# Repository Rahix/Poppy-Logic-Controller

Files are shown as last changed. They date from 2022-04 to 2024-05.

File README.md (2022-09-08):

<h2 align="center">Poppy Logic Controller</h2>
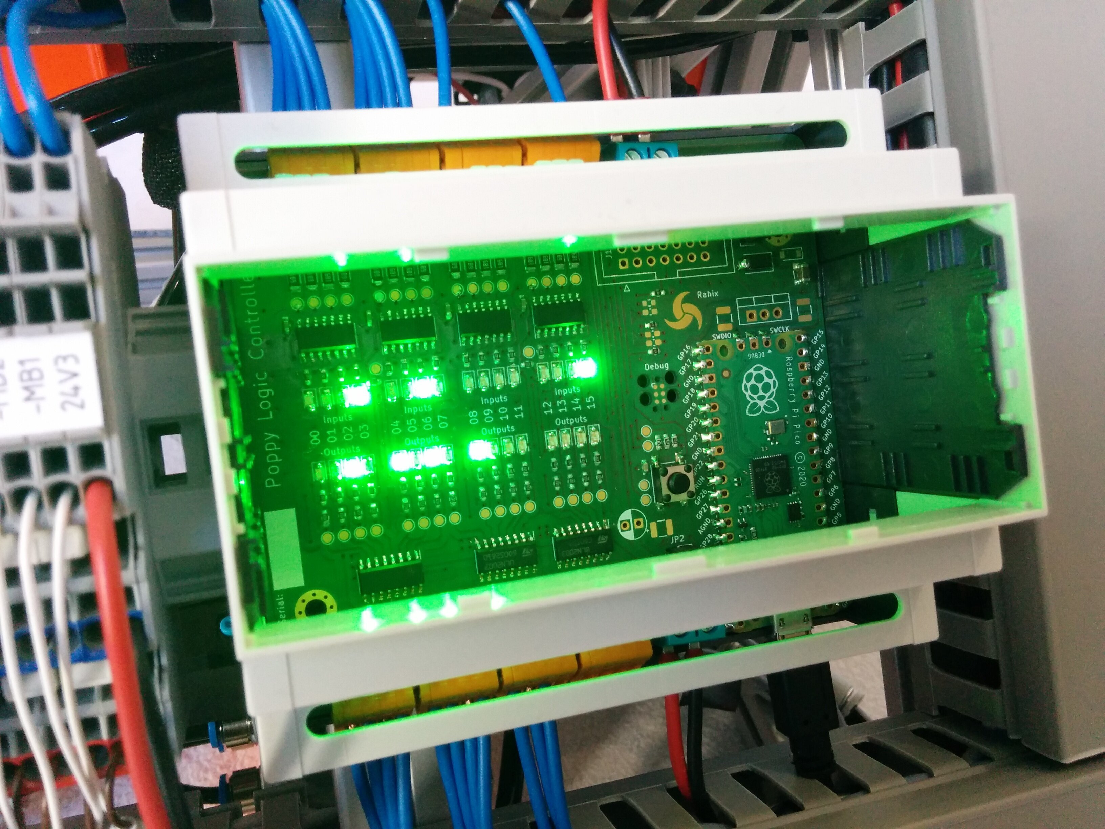
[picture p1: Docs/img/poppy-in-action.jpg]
Poppy Logic Controller


---

The _Poppy Logic Controller_ is a budget PLC (Programmable Logic Controller).
Importantly, it is only an I/O board without any PLC programming environment
(so far).  It isn't designed to be super robust but instead to use minimal
components while still staying compatible with standard industrial 24V DC
control systems.

I release the _Poppy Logic Controller_ as open hardware in hopes that others
who need a cheap solution for controlling industrial 24V DC equipment find it
useful.  _This is not a commercially viable PLC alternative._

If you want to know more about the background of this project and details of
the design, you might be interested in the blog post I wrote about it: [**Poppy
Logic Controller**][poppy-blog]

### Features
- Designed for 24V DC systems as most commonly found in modern controls
  applications.
- 16 DI (digital inputs) in a **Sinking Input** configuration.
- 16 DO (digital outputs) in a **Sinking Output** configuration.
- Firmware stubs in [Rust][fw-rust], [MicroPython][fw-mp], and [IEC 61131-3
  _Structured Text_][fw-iec].

<small>Learn more about sinking/sourcing I/O [here][realpars-input] and
[here][realpars-output] or from [my blog-post about this
project][poppy-blog].</small>

### Non-Features
- I/Os are **not** galvanically isolated.  Honestly, the isolators would
  probably be more expensive than the MCU so there is not much incentive to
  implement isolation anyway.
- The board currently does not have any communication interfaces apart from the
  Pico's USB port.  If you need to interface with anything, you might need to
  either update the board design or connect an additional mod onto the `J12`
  header.

### Building Your Own
Rendered versions of the schematic and BOM can be found here:

- [Rendered Schematic](./Docs/PoppyIO.pdf)
- [Rendered BOM](https://rahix.github.io/Poppy-Logic-Controller/Docs/PoppyIO_bom_D.html)
- [Rendered Interactive BOM](https://rahix.github.io/Poppy-Logic-Controller/Docs/PoppyIO_ibom_D.html)

#### Parts
Supplier for almost all parts of this project was [Reichelt Elektronik] (no
affiliation or sponsorship here, purely personal choice).  I've tried
reconstructing the BOM with all the Reichelt SKUs so you can painlessly get all
you need from one place if you so desire.  There is a column in the BOMs linked
above with all the information you need.

#### Additional Components
Beyond the PCB's BOM, you will need a few more components.  After all, you
probably want the nice feeling of mounting your controller on a DIN-rail, don't
you?

1. The enclosure, which is an `APRA-NORM 449-360-65` (Reichelt `APRA DB6 OBK`)
2. Optionally, a lid for the enclosure, like `APRA-NORM 449-360-12` (Reichelt
   `APRA 449-360-12`). Also available in other colors.
3. A few (2) jumpers (Reichelt `JUMPER 2,54 SW`)

#### Hardware Revisions
In the design files, you'll find the latest revision **D**.  I suggest using
that one although it is not exactly the version I have built.  My (2) boards
are built from revision **B** with one populated like revision **C** and one
populated like revision **D**.  You can read the [changelog][poppy-changelog]
for details of the differences.

#### Programming It
This repository contains a bare-bones firmware in Rust and MicroPython to get
started.  Or, if you have a background in automation, you can program the Poppy
Logic Controller in _ST_ (_Structured Text_) using the IEC 61131-3 firmware.
Check the READMEs for more info on that:

- [Firmware-Rust][fw-rust]
- [Firmware-MicroPython][fw-mp]
- [Firmware-IEC][fw-iec]

#### Not using the Pico
If you need a different microcontroller, you can drop the Raspberry Pi Pico and
instead solder the `J12` header.  You can then connect whatever controller you
desire and use the I²C bus (and interrupt lines) to interact with the I/O.

---

If you want to build your own but you are unsure or you have questions about
anything, feel free to contact me to get it sorted out!

## License
- The hardware design files (everything in `Hardware/`) are licensed under the
  [CERN-OHL-W](LICENSE-HARDWARE).
- The firmware stubs (everything in `Firmware-*/`) are licensed under
  [MIT](LICENSE-SOFTWARE).

[Reichelt Elektronik]: https://www.reichelt.de/
[poppy-blog]: https://blog.rahix.de/poppy-logic-controller/
[poppy-changelog]: ./Hardware/PoppyIO/CHANGELOG.md
[realpars-input]: https://realpars.com/sinking-and-sourcing/
[realpars-output]: https://realpars.com/sinking-output/
[fw-rust]: ./Firmware-Rust/
[fw-mp]: ./Firmware-MicroPython/
[fw-iec]: ./Firmware-IEC/

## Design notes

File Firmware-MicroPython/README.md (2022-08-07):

MicroPython Firmware for Poppy Logic Controller
-----------------------------------------------
In this directory, you can find a bare-bones MicroPython firmware for the Poppy
Logic Controller.  You can use this as a starting point for developing your own
programs.

To get started, you need to install MicroPython on the Raspberry Pi Pico.
Information about this can be found here:
<https://www.raspberrypi.com/documentation/microcontrollers/micropython.html>

Next, install the `mpremote` tool to interact with the Pico:

```bash
pin install mpremote
```

Next, if you just want to try out some code, you can upload it to the Pico like
this:

```bash
mpremote run poppy.py
```

If you want to upload the program permanently, so the Pico automatically runs
it on power-on, use this command:

```bash
mpremote cp poppy.py :main.py
```

**Note the `:` before `main.py`!**

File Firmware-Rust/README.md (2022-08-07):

Rust Firmware for Poppy Logic Controller
----------------------------------------
In this directory, you can find a bare-bones Rust firmware for the Poppy Logic
Controller.  You can use this as a starting point for developing your own
programs.

To run this firmware, first install `elf2uf2-rs`, the tool to flash firmware
onto the Raspberry Pi Pico:

```bash
cargo install elf2uf2-rs
```

Then, put the Pico into bootloader mode by first pressing the `BOOTSEL` button
and then, while keeping it held down, pressing the reset button.

Now you're ready to upload your Rust program using a simple

```bash
cargo run
```

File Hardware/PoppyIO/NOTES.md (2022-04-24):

Notes & ToDo List for the IO Board
==================================

### Inputs
- [x] Indicator LEDs
- [x] LED series resistor verification: ~1mA
- [x] ESD safety: 74VHC14 has protection
- [x] Re-verify current and voltage
- [x] Verify limiting values: Maximum input voltage for 5.5V out is 27.6V.
  Limiting value (7V) is reached at 35V.
- [x] Verify logic step-down:  Multiple 74VHC14 data-sheets mention that it can
  be used to step down to Vcc.
- [x] Defined initial state for inverters?
  - 680R pulls down to GND

### Outputs
- [x] Indicator LEDs
- [x] LED series resistor verification ~1mA
- [x] Driver: ULN2003A
- [x] Compatibility with inductive loads
  - Compatible as long as 24V supply is connected (freewheeling diodes included
    in driver package).
- [x] Check drive capability of port-expander (LEDs + drivers)
- [x] ESD safety: ULN2003A has protection
- [x] defined initial state for drivers?
  - Added 10k pull-downs.
- [x] Must use a smaller polyfuse footprint

### Power Supply
- [x] Add 24V to 5/3.3V step down or power from 5V?
- [x] Screw-in terminals: Using Phoenix screw terminals for power

### Pico MCU
- [x] Reset Button
- [x] Additional IO?
  - Added a UART for the second board, just in case.

### Misc
- [x] I2C addresses
- [x] Mounting holes
- [x] Board-to-Board Connector Pinout

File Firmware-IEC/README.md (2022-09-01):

IEC 61131-3 Firmware for Poppy Logic Controller
-----------------------------------------------
The firmware in this directory allows writing control programs for the Poppy
Logic Controller in the IEC 61131-3 textual language _ST_ (_Structured Text_).

This is made possible by the [matiec] open-source 61131-3 compiler.  This
compiler is used to compile the _ST_ code into the C language from where it
is then linked against a Rust firmware which drives the I/O.

### Running It
The build process is entirely driven by cargo.  [matiec] is installed
automatically on first build.  The only dependency you need is, as for the Rust
firmware, `elf2uf2-rs`:

```bash
cargo install elf2uf2-rs
```

Then, put the Pico into bootloader mode by first pressing the `BOOTSEL` button
and then, while keeping it held down, pressing the reset button.

Now you can build and deploy your 61131-3 firmware:

```bash
cargo run
```

### Programming Quickstart
You might want to read up on the basics of _ST_ somewhere first.  I am going to
detail some [matiec] and Poppy Logic specific things in this section of the
README.

The program is found in [`src/main.st`][main.st].  In contrast to a lot of PLC
programming IDEs, the entire _ST_ program must be written here, including the
top-level program and configuration (which is usually handled in GUI).  You can
take the existing code as a basis. Your top-level code goes into the body of
the `PROGRAM`.

Further tasks and function blocks can also be added to `main.st`.
Alternatively, you can put them in separate files and include those using:

```text
{#include "filename.st"}
```

For I/O, the following tags exist and map to the Poppy Logic Controllers 16
inputs and 16 outputs:

- Inputs: `%IX00`, `%IX01`, `%IX02`, `%IX03`, `%IX04`, `%IX05`, `%IX06`,
  `%IX07`, `%IX08`, `%IX09`, `%IX10`, `%IX11`, `%IX12`, `%IX13`, `%IX14`,
  `%IX15`
- Outputs: `%QX00`, `%QX01`, `%QX02`, `%QX03`, `%QX04`, `%QX05`, `%QX06`,
  `%QX07`, `%QX08`, `%QX09`, `%QX10`, `%QX11`, `%QX12`, `%QX13`, `%QX14`,
  `%QX15`

Byte-access or word-access to these tags is not possible.

### Modbus
This firmware also comes with a [Modbus RTU] interface for interaction with
other devices.  The interface is available over USB, where the Poppy Logic
Controller will announce itself as a serial port.

A few registers are mapped to Modbus for communication:

- Modbus Coils 0 - 15 of unit 1 are mapped to `%MX00` - `%MX15`.
- Modbus Holding Registers 0 - 15 of unit 1 are mapped to `%MW00` - `%MW15`.
  Holding registers are 16 bits wide.

Additionally, the state of all inputs and outputs is available _read-only_
through Modbus discrete inputs:

- Inputs `%IX00` - `%IX15` are mapped to discrete inputs 0 - 15.
- Outputs `%QX00` - `%QX15` are mapped to discrete inputs 16 - 31.

(This may be useful for visualization purposes).

As a quick example, using the [pymodbus REPL] you can set coils or dump the
state of inputs and outputs:

```console
$ pymodbus.console serial --port /dev/ttyACM0

> # Set a coil
> client.write_coil unit=1 address=0 value=1
> # And reset it again
> client.write_coil unit=1 address=0 value=0

> # Or dump all physical inputs and outputs
> client.read_discrete_inputs unit=1 address=0 count=32
{
    "bits": [
        false,
        false,
        ...
```

### Modbus Monitor GUI Example
To demonstrate the Modbus communication, I added a small GUI example:
[`modbus_monitor.py`](./modbus_monitor.py)

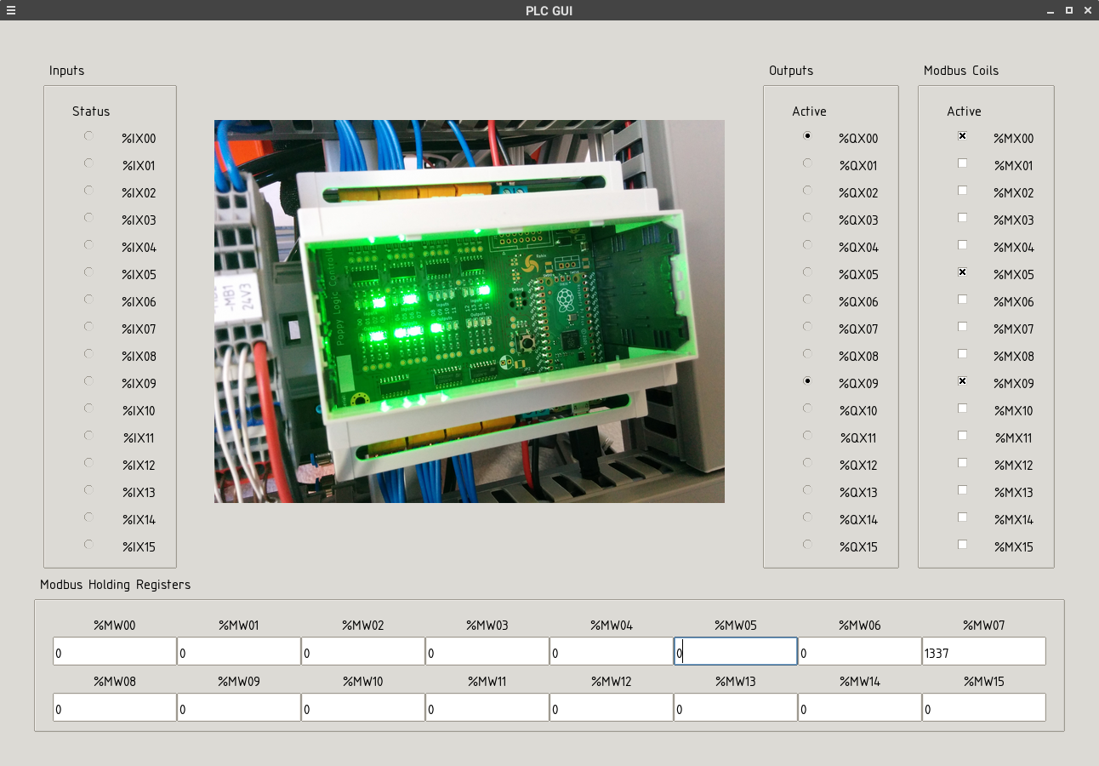
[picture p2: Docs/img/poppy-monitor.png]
Image of the GUI


[matiec]: https://github.com/beremiz/matiec
[main.st]: src/main.st
[Modbus RTU]: https://en.wikipedia.org/wiki/Modbus
[pymodbus REPL]: https://pymodbus.readthedocs.io/en/latest/source/library/REPL.html

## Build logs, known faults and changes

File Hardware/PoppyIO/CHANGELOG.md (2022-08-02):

## Revision D - 2022-08-02
- Drop _DNP_ note from LM78xx regulator and its capacitors.  The regulator is
  used to step-down the 24V input to 5V for the Raspberry Pi Pico.  Not using
  the regulator means a separate 5V supply is needed which is pretty pointless.
- Removed the screw-terminal J9 for an external 5V supply.
- Switched Screw-Terminal for 24V supply to a 2-pin variant.

## Revision C - 2022-06-26
- Fixup wrong resistor values in DI stage.  The 680Ω resistors were meant to be
  820Ω from the beginning but this was not copied correctly.  With the wrong
  value, the DI limiting values are slightly off from what is specified in the
  schematic.

## Revision B - 2022-04-25
- Switch to a 14-pin IDC connector.

## Revision A - 2022-04-24
Initial.

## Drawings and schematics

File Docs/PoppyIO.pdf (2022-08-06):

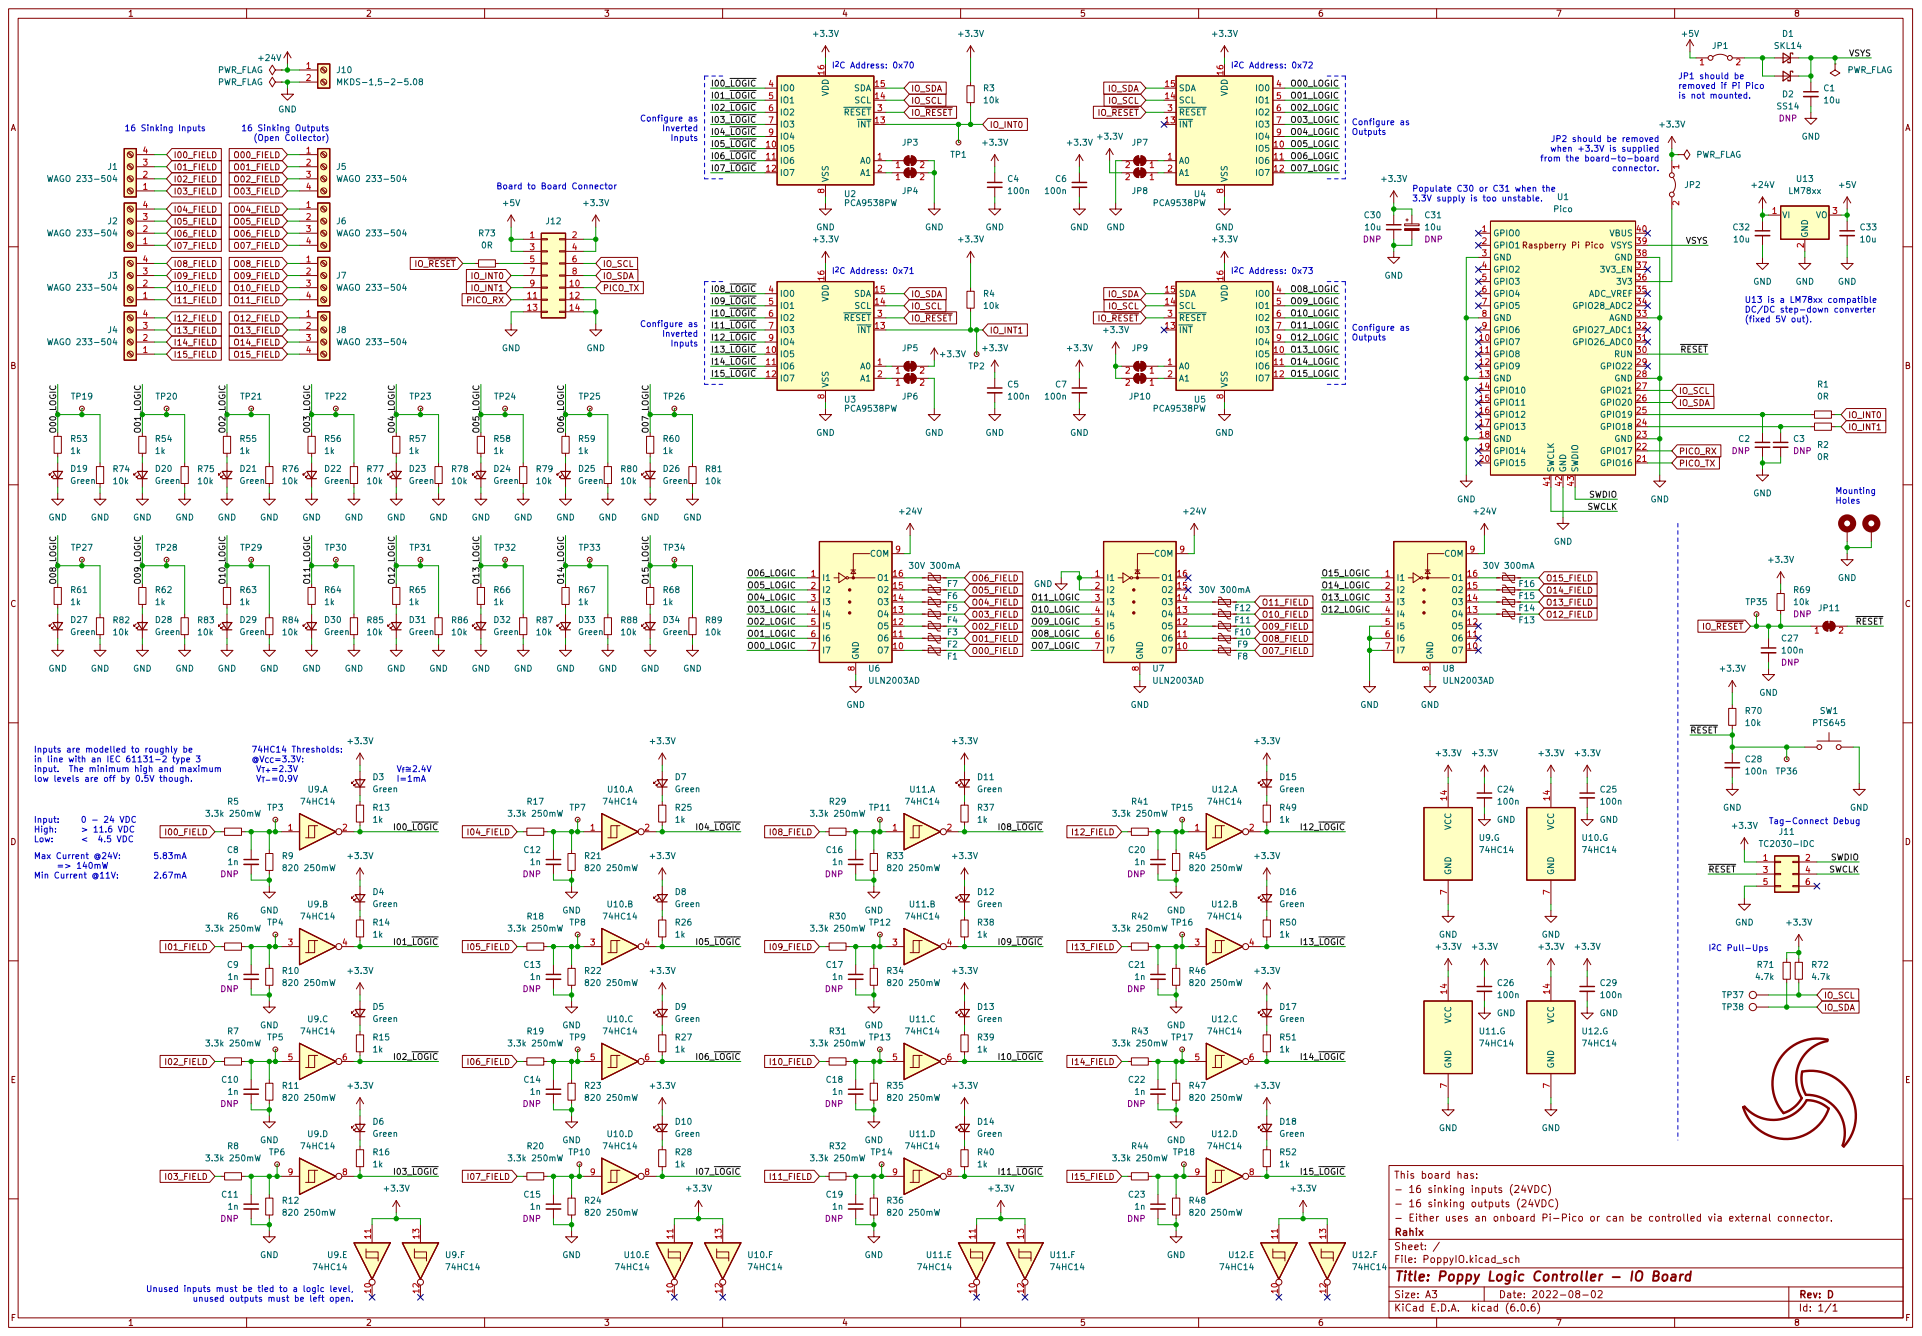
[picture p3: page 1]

removed if Pi Pico
is not mounted.

JP2 should be removed when +3.3V is supplied

from the board-to-board

U13 is a LM78xx compatible
DC/DC step-down converter
(fixed 5V out).
C3 DNP R1

Inputs are modelled to roughly be
in line with an IEC 61131-2 type 3
input. The minimum high and maximum
low levels are off by 0.5V though.

- 16 sinking inputs (24VDC) This board has:

- Either uses an onboard Pi-Pico or can be controlled via external connector. - 16 sinking outputs (24VDC)

File: PoppyIO.kicad_sch Sheet: / Rahix

Id: 1/1 Title: Poppy Logic Controller - IO Board

Unused inputs must be tied to a logic level,

unused outputs must be left open.

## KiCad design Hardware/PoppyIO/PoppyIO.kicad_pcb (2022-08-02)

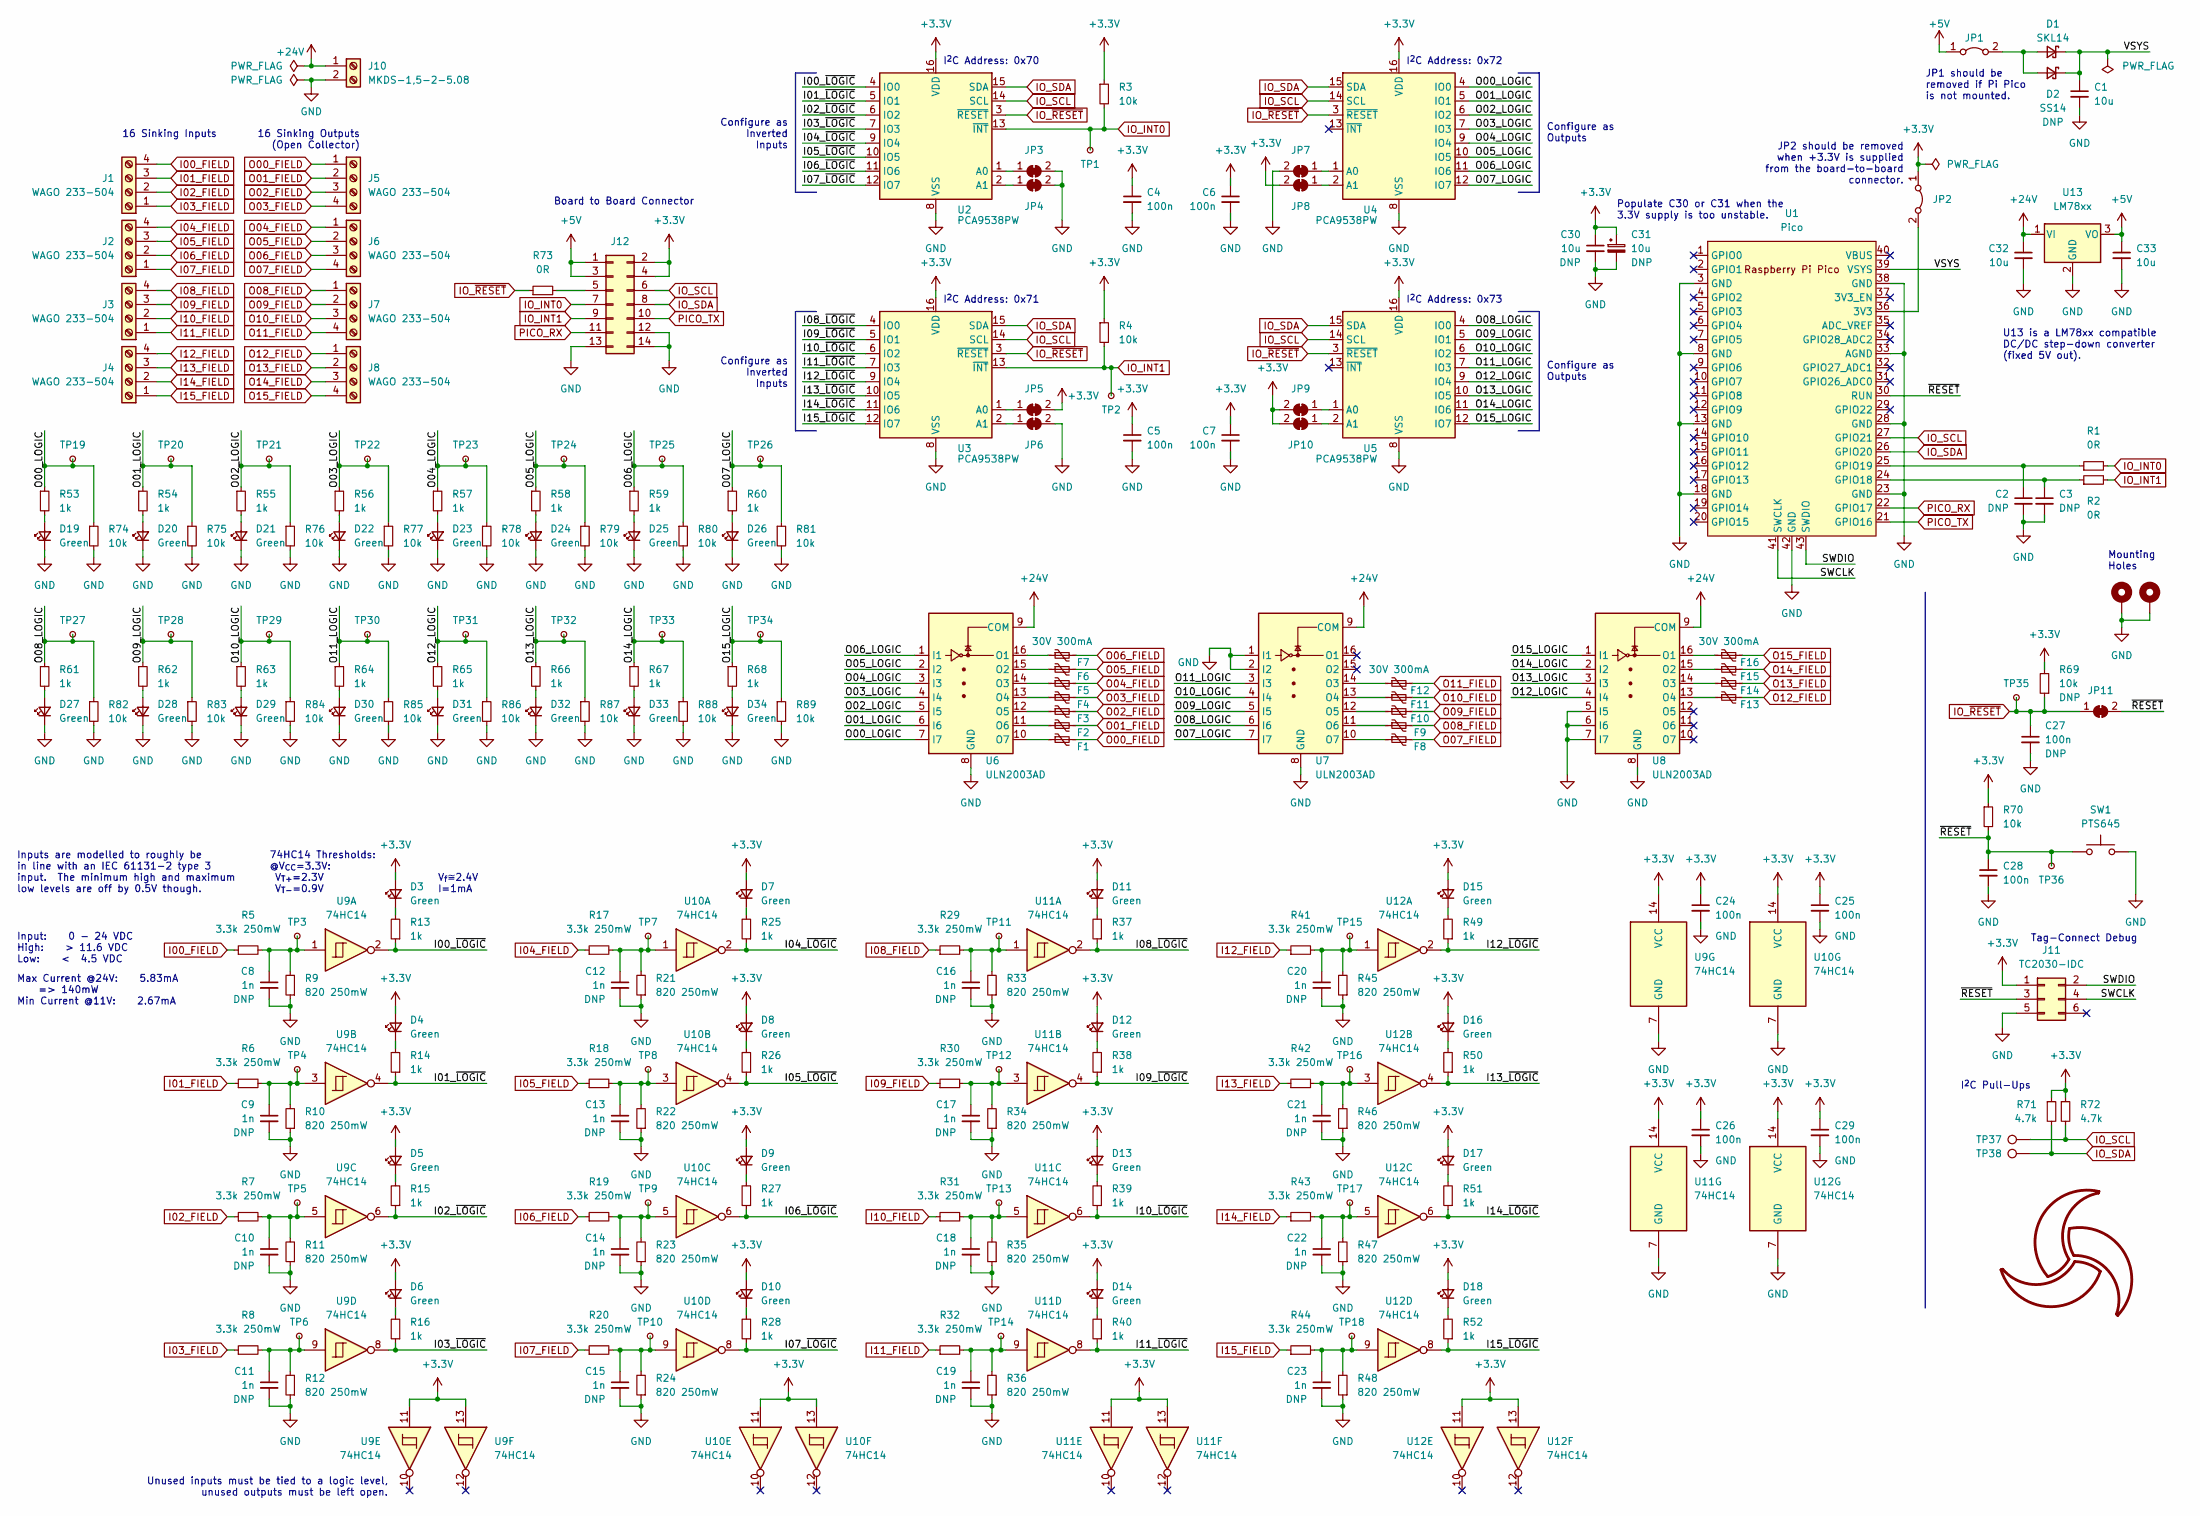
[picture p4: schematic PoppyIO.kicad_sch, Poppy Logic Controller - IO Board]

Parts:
C1, C30, C32, C33: 10u; C_1210_3225Metric
C2, C3: C_0603_1608Metric_Pad1.08x0.95mm_HandSolder
C4, C5, C6, C7, C24, C25, C26, C27, C28, C29: 100n; C_0603_1608Metric_Pad1.08x0.95mm_HandSolder
C8, C9, C10, C11, C12, C13, C14, C15, C16, C17, C18, C19, C20, C21, C22, C23: 1n; C_0805_2012Metric
C31: 10u; CP_Radial_D5.0mm_P2.50mm
D1: SKL14; D_SOD-123
D2: SS14; D_SMA
D3, D4, D5, D6, D7, D8, D9, D10, D11, D12, D13, D14, D15, D16, D17, D18, D19, D20, D21, D22, D23, D24, D25, D26, D27, D28, D29, D30, D31, D32, D33, D34: Green; LED_0805_2012Metric_Pad1.15x1.40mm_HandSolder
F1, F2, F3, F4, F5, F6, F7, F8, F9, F10, F11, F12, F13, F14, F15, F16: 30V 300mA; Fuse_1210_3225Metric_Pad1.42x2.65mm_HandSolder
H1, H2: MountingHole_Pad; MountingHole_3.2mm_M3_Pad_Via
J1, J2, J3, J4, J5, J6, J7, J8: WAGO 233-504; WAGO_233-204
J10: MKDS-1,5-2-5.08; TerminalBlock_Phoenix_MKDS-1,5-2-5.08_1x02_P5.08mm_Horizont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
J11: TC2030-IDC; Tag-Connect_TC2030-IDC-FP_2x03_P1.27mm_Vertical
J12: Conn_02x07_Odd_Even; IDC-Header_2x07_P2.54mm_Vertical
JP1, JP2: PinHeader_1x02_P2.54mm_Vertical
JP3, JP4, JP5, JP6, JP7, JP8, JP9, JP10, JP11: SolderJumper_2_Bridged; SolderJumper-2_P1.3mm_Bridged_RoundedPad1.0x1.5mm
R1, R2, R73: 0R; R_0603_1608Metric
R3, R4, R69, R70, R74, R75, R76, R77, R78, R79, R80, R81, R82, R83, R84, R85, R86, R87, R88, R89: 10k; R_0603_1608Metric
R5, R6, R7, R8, R17, R18, R19, R20, R29, R30, R31, R32, R41, R42, R43, R44: 3.3k 250mW; R_1206_3216Metric
R9, R10, R11, R12, R21, R22, R23, R24, R33, R34, R35, R36, R45, R46, R47, R48: 820 250mW; R_1206_3216Metric
R13, R14, R15, R16, R25, R26, R27, R28, R37, R38, R39, R40, R49, R50, R51, R52, R53, R54, R55, R56, R57, R58, R59, R60, R61, R62, R63, R64, R65, R66, R67, R68: 1k; R_0603_1608Metric
R71, R72: 4.7k; R_0603_1608Metric_Pad0.98x0.95mm_HandSolder
SW1: PTS645; SW_SPST_PTS645
SYM1: SYM_Rahix
TP1, TP2, TP3, TP4, TP5, TP6, TP7, TP8, TP9, TP10, TP11, TP12, TP13, TP14, TP15, TP16, TP17, TP18, TP19, TP20, TP21, TP22, TP23, TP24, TP25, TP26, TP27, TP28, TP29, TP30, TP31, TP32, TP33, TP34, TP35, TP36: TestPoint_Small; TestPoint_Pad_D1.5mm
TP37, TP38: TestPoint; TestPoint_Pad_D1.5mm
U1: Pico; RPi_Pico_SMD_TH
U2, U3, U4, U5: PCA9538PW; TSSOP-16_4.4x5mm_P0.65mm
U6, U7, U8: ULN2003AD; SOIC-16_3.9x9.9mm_P1.27mm
U9, U10, U11, U12: 74HC14; SOIC-14_3.9x8.7mm_P1.27mm
U13: LM78xx; TO-220-3_Vertical_Clearance

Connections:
+3.3V: C4.1, C5.1, C6.1, C7.1, C24.1, C25.1, C26.1, C29.1, C30.1, C31.1, D3.2 (A), D4.2 (A), D5.2 (A), D6.2 (A), D7.2 (A), D8.2 (A), D9.2 (A), D10.2 (A), D11.2 (A), D12.2 (A), D13.2 (A), D14.2 (A), D15.2 (A), D16.2 (A), D17.2 (A), D18.2 (A), J11.1, J12.2, J12.4, JP2.1 (A), JP5.2 (B), JP8.2 (B), JP9.2 (B), JP10.2 (B), R3.1, R4.1, R69.2, R70.1, R71.1, R72.1, U2.16 (VDD), U3.16 (VDD), U4.16 (VDD), U5.16 (VDD), U9.11, U9.13, U9.14 (VCC), U10.11, U10.13, U10.14 (VCC), U11.11, U11.13, U11.14 (VCC), U12.11, U12.13, U12.14 (VCC)
+5V: C33.1, J12.1, J12.3, JP1.1 (A), U13.3 (VO)
+24V: C32.1, J10.1, U6.9 (COM), U7.9 (COM), U8.9 (COM), U13.1 (VI)
/I00_~LOGIC: R13.1, U2.4 (IO0), U9.2
/I01_~LOGIC: R14.1, U2.5 (IO1), U9.4
/I02_~LOGIC: R15.1, U2.6 (IO2), U9.6
/I03_~LOGIC: R16.1, U2.7 (IO3), U9.8
/I04_~LOGIC: R25.1, U2.9 (IO4), U10.2
/I05_~LOGIC: R26.1, U2.10 (IO5), U10.4
/I06_~LOGIC: R27.1, U2.11 (IO6), U10.6
/I07_~LOGIC: R28.1, U2.12 (IO7), U10.8
/I08_~LOGIC: R37.1, U3.4 (IO0), U11.2
/I09_~LOGIC: R38.1, U3.5 (IO1), U11.4
/I10_~LOGIC: R39.1, U3.6 (IO2), U11.6
/I11_~LOGIC: R40.1, U3.7 (IO3), U11.8
/I12_~LOGIC: R49.1, U3.9 (IO4), U12.2
/I13_~LOGIC: R50.1, U3.10 (IO5), U12.4
/I14_~LOGIC: R51.1, U3.11 (IO6), U12.6
/I15_~LOGIC: R52.1, U3.12 (IO7), U12.8
/O00_LOGIC: R53.1, R74.1, TP19.1, U4.4 (IO0), U6.7 (I7)
/O01_LOGIC: R54.1, R75.1, TP20.1, U4.5 (IO1), U6.6 (I6)
/O02_LOGIC: R55.1, R76.1, TP21.1, U4.6 (IO2), U6.5 (I5)
/O03_LOGIC: R56.1, R77.1, TP22.1, U4.7 (IO3), U6.4 (I4)
/O04_LOGIC: R57.1, R78.1, TP23.1, U4.9 (IO4), U6.3 (I3)
/O05_LOGIC: R58.1, R79.1, TP24.1, U4.10 (IO5), U6.2 (I2)
/O06_LOGIC: R59.1, R80.1, TP25.1, U4.11 (IO6), U6.1 (I1)
/O07_LOGIC: R60.1, R81.1, TP26.1, U4.12 (IO7), U7.7 (I7)
/O08_LOGIC: R61.1, R82.1, TP27.1, U5.4 (IO0), U7.6 (I6)
/O09_LOGIC: R62.1, R83.1, TP28.1, U5.5 (IO1), U7.5 (I5)
/O10_LOGIC: R63.1, R84.1, TP29.1, U5.6 (IO2), U7.4 (I4)
/O11_LOGIC: R64.1, R85.1, TP30.1, U5.7 (IO3), U7.3 (I3)
/O12_LOGIC: R65.1, R86.1, TP31.1, U5.9 (IO4), U8.4 (I4)
/O13_LOGIC: R66.1, R87.1, TP32.1, U5.10 (IO5), U8.3 (I3)
/O14_LOGIC: R67.1, R88.1, TP33.1, U5.11 (IO6), U8.2 (I2)
/O15_LOGIC: R68.1, R89.1, TP34.1, U5.12 (IO7), U8.1 (I1)
/SWCLK: J11.4, U1.41 (SWCLK)
/SWDIO: J11.2, U1.43 (SWDIO)
/VSYS: C1.1, D1.1 (K), D2.1 (K), U1.39 (VSYS)
/~RESET: C28.1, J11.3, JP11.2 (B), R70.2, SW1.1, TP36.1, U1.30 (RUN)
GND: C1.2, C2.2, C3.2, C4.2, C5.2, C6.2, C7.2, C8.2, C9.2, C10.2, C11.2, C12.2, C13.2, C14.2, C15.2, C16.2, C17.2, C18.2, C19.2, C20.2, C21.2, C22.2, C23.2, C24.2, C25.2, C26.2, C27.2, C28.2, C29.2, C30.2, C31.2, C32.2, C33.2, D19.1 (K), D20.1 (K), D21.1 (K), D22.1 (K), D23.1 (K), D24.1 (K), D25.1 (K), D26.1 (K), D27.1 (K), D28.1 (K), D29.1 (K), D30.1 (K), D31.1 (K), D32.1 (K), D33.1 (K), D34.1 (K), H1.1, H2.1, J10.2, J11.5, J12.12, J12.13, J12.14, JP3.2 (B), JP4.2 (B), JP6.2 (B), JP7.2 (B), R9.1, R10.1, R11.1, R12.1, R21.1, R22.1, R23.1, R24.1, R33.1, R34.1, R35.1, R36.1, R45.1, R46.1, R47.1, R48.1, R74.2, R75.2, R76.2, R77.2, R78.2, R79.2, R80.2, R81.2, R82.2, R83.2, R84.2, R85.2, R86.2, R87.2, R88.2, R89.2, SW1.2, U1.3 (GND), U1.8 (GND), U1.13 (GND), U1.18 (GND), U1.23 (GND), U1.28 (GND), U1.33 (AGND), U1.38 (GND), U1.42 (GND), U2.8 (VSS), U3.8 (VSS), U4.8 (VSS), U5.8 (VSS), U6.8 (GND), U7.1 (I1), U7.2 (I2), U7.8 (GND), U8.5 (I5), U8.6 (I6), U8.7 (I7), U8.8 (GND), U9.7 (GND), U10.7 (GND), U11.7 (GND), U12.7 (GND), U13.2 (GND)
I00_FIELD: J1.4, R5.1
I01_FIELD: J1.3, R6.1
I02_FIELD: J1.2, R7.1
I03_FIELD: J1.1, R8.1
I04_FIELD: J2.4, R17.1
I05_FIELD: J2.3, R18.1
I06_FIELD: J2.2, R19.1
I07_FIELD: J2.1, R20.1
I08_FIELD: J3.4, R29.1
I09_FIELD: J3.3, R30.1
I10_FIELD: J3.2, R31.1
I11_FIELD: J3.1, R32.1
I12_FIELD: J4.4, R41.1
I13_FIELD: J4.3, R42.1
I14_FIELD: J4.2, R43.1
I15_FIELD: J4.1, R44.1
IO_INT0: J12.7, R1.2, R3.2, TP1.1, U2.13 (~INT)
IO_INT1: J12.9, R2.2, R4.2, TP2.1, U3.13 (~INT)
IO_SCL: J12.6, R72.2, TP37.1, U1.27 (GPIO21), U2.14 (SCL), U3.14 (SCL), U4.14 (SCL), U5.14 (SCL)
IO_SDA: J12.8, R71.2, TP38.1, U1.26 (GPIO20), U2.15 (SDA), U3.15 (SDA), U4.15 (SDA), U5.15 (SDA)
IO_~RESET: C27.1, JP11.1 (A), R69.1, R73.1, TP35.1, U2.3 (~RESET), U3.3 (~RESET), U4.3 (~RESET), U5.3 (~RESET)
unnamed: C2.1, R1.1, U1.25 (GPIO19)
unnamed: C3.1, R2.1, U1.24 (GPIO18)
unnamed: C8.1, R5.2, R9.2, TP3.1, U9.1
unnamed: C9.1, R6.2, R10.2, TP4.1, U9.3
unnamed: C10.1, R7.2, R11.2, TP5.1, U9.5
unnamed: C11.1, R8.2, R12.2, TP6.1, U9.9
unnamed: C12.1, R17.2, R21.2, TP7.1, U10.1
unnamed: C13.1, R18.2, R22.2, TP8.1, U10.3
unnamed: C14.1, R19.2, R23.2, TP9.1, U10.5
unnamed: C15.1, R20.2, R24.2, TP10.1, U10.9
unnamed: C16.1, R29.2, R33.2, TP11.1, U11.1
unnamed: C17.1, R30.2, R34.2, TP12.1, U11.3
unnamed: C18.1, R31.2, R35.2, TP13.1, U11.5
unnamed: C19.1, R32.2, R36.2, TP14.1, U11.9
unnamed: C20.1, R41.2, R45.2, TP15.1, U12.1
unnamed: C21.1, R42.2, R46.2, TP16.1, U12.3
unnamed: C22.1, R43.2, R47.2, TP17.1, U12.5
unnamed: C23.1, R44.2, R48.2, TP18.1, U12.9
unnamed: D1.2 (A), D2.2 (A), JP1.2 (B)
unnamed: D3.1 (K), R13.2
unnamed: D4.1 (K), R14.2
unnamed: D5.1 (K), R15.2
unnamed: D6.1 (K), R16.2
unnamed: D7.1 (K), R25.2
unnamed: D8.1 (K), R26.2
unnamed: D9.1 (K), R27.2
unnamed: D10.1 (K), R28.2
unnamed: D11.1 (K), R37.2
unnamed: D12.1 (K), R38.2
unnamed: D13.1 (K), R39.2
unnamed: D14.1 (K), R40.2
unnamed: D15.1 (K), R49.2
unnamed: D16.1 (K), R50.2
unnamed: D17.1 (K), R51.2
unnamed: D18.1 (K), R52.2
unnamed: D19.2 (A), R53.2
unnamed: D20.2 (A), R54.2
unnamed: D21.2 (A), R55.2
unnamed: D22.2 (A), R56.2
unnamed: D23.2 (A), R57.2
unnamed: D24.2 (A), R58.2
unnamed: D25.2 (A), R59.2
unnamed: D26.2 (A), R60.2
unnamed: D27.2 (A), R61.2
unnamed: D28.2 (A), R62.2
unnamed: D29.2 (A), R63.2
unnamed: D30.2 (A), R64.2
unnamed: D31.2 (A), R65.2
unnamed: D32.2 (A), R66.2
unnamed: D33.2 (A), R67.2
unnamed: D34.2 (A), R68.2
unnamed: F1.1, U6.10 (O7)
unnamed: F2.1, U6.11 (O6)
unnamed: F3.1, U6.12 (O5)
unnamed: F4.1, U6.13 (O4)
unnamed: F5.1, U6.14 (O3)
unnamed: F6.1, U6.15 (O2)
unnamed: F7.1, U6.16 (O1)
unnamed: F8.1, U7.10 (O7)
unnamed: F9.1, U7.11 (O6)
unnamed: F10.1, U7.12 (O5)
unnamed: F11.1, U7.13 (O4)
unnamed: F12.1, U7.14 (O3)
unnamed: F13.1, U8.13 (O4)
unnamed: F14.1, U8.14 (O3)
unnamed: F15.1, U8.15 (O2)
unnamed: F16.1, U8.16 (O1)
unnamed: J12.5, R73.2
unnamed: JP2.2 (B), U1.36 (3V3)
unnamed: JP3.1 (A), U2.1 (A0)
unnamed: JP4.1 (A), U2.2 (A1)
unnamed: JP5.1 (A), U3.1 (A0)
unnamed: JP6.1 (A), U3.2 (A1)
unnamed: JP7.1 (A), U4.1 (A0)
unnamed: JP8.1 (A), U4.2 (A1)
unnamed: JP9.1 (A), U5.1 (A0)
unnamed: JP10.1 (A), U5.2 (A1)
O00_FIELD: F1.2, J5.1
O01_FIELD: F2.2, J5.2
O02_FIELD: F3.2, J5.3
O03_FIELD: F4.2, J5.4
O04_FIELD: F5.2, J6.1
O05_FIELD: F6.2, J6.2
O06_FIELD: F7.2, J6.3
O07_FIELD: F8.2, J6.4
O08_FIELD: F9.2, J7.1
O09_FIELD: F10.2, J7.2
O10_FIELD: F11.2, J7.3
O11_FIELD: F12.2, J7.4
O12_FIELD: F13.2, J8.1
O13_FIELD: F14.2, J8.2
O14_FIELD: F15.2, J8.3
O15_FIELD: F16.2, J8.4
PICO_RX: J12.11, U1.22 (GPIO17)
PICO_TX: J12.10, U1.21 (GPIO16)

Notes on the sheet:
Configure as Outputs
16 Sinking Inputs
Input: 0 - 24 VDC High: > 11.6 VDC Low: < 4.5 VDC
U13 is a LM78xx compatible DC/DC step-down converter (fixed 5V out).
JP1 should be removed if Pi Pico is not mounted.
Inputs are modelled to roughly be in line with an IEC 61131-2 type 3 input. The minimum high and maximum low levels are off by 0.5V though.
Unused inputs must be tied to a logic level, unused outputs must be left open.
I^{2}C Address: 0x70
I^{2}C Address: 0x73
I^{2}C Address: 0x72
74HC14 Thresholds: @V_{CC}=3.3V: V_{T+}=2.3V V_{T-}=0.9V
I^{2}C Address: 0x71
Tag-Connect Debug
Max Current @24V: 5.83mA => 140mW Min Current @11V: 2.67mA
Board to Board Connector
Configure as Inverted Inputs
I^{2}C Pull-Ups
16 Sinking Outputs (Open Collector)
Populate C30 or C31 when the 3.3V supply is too unstable.
V_{f}≅2.4V I=1mA
JP2 should be removed when +3.3V is supplied from the board-to-board connector.
Mounting Holes

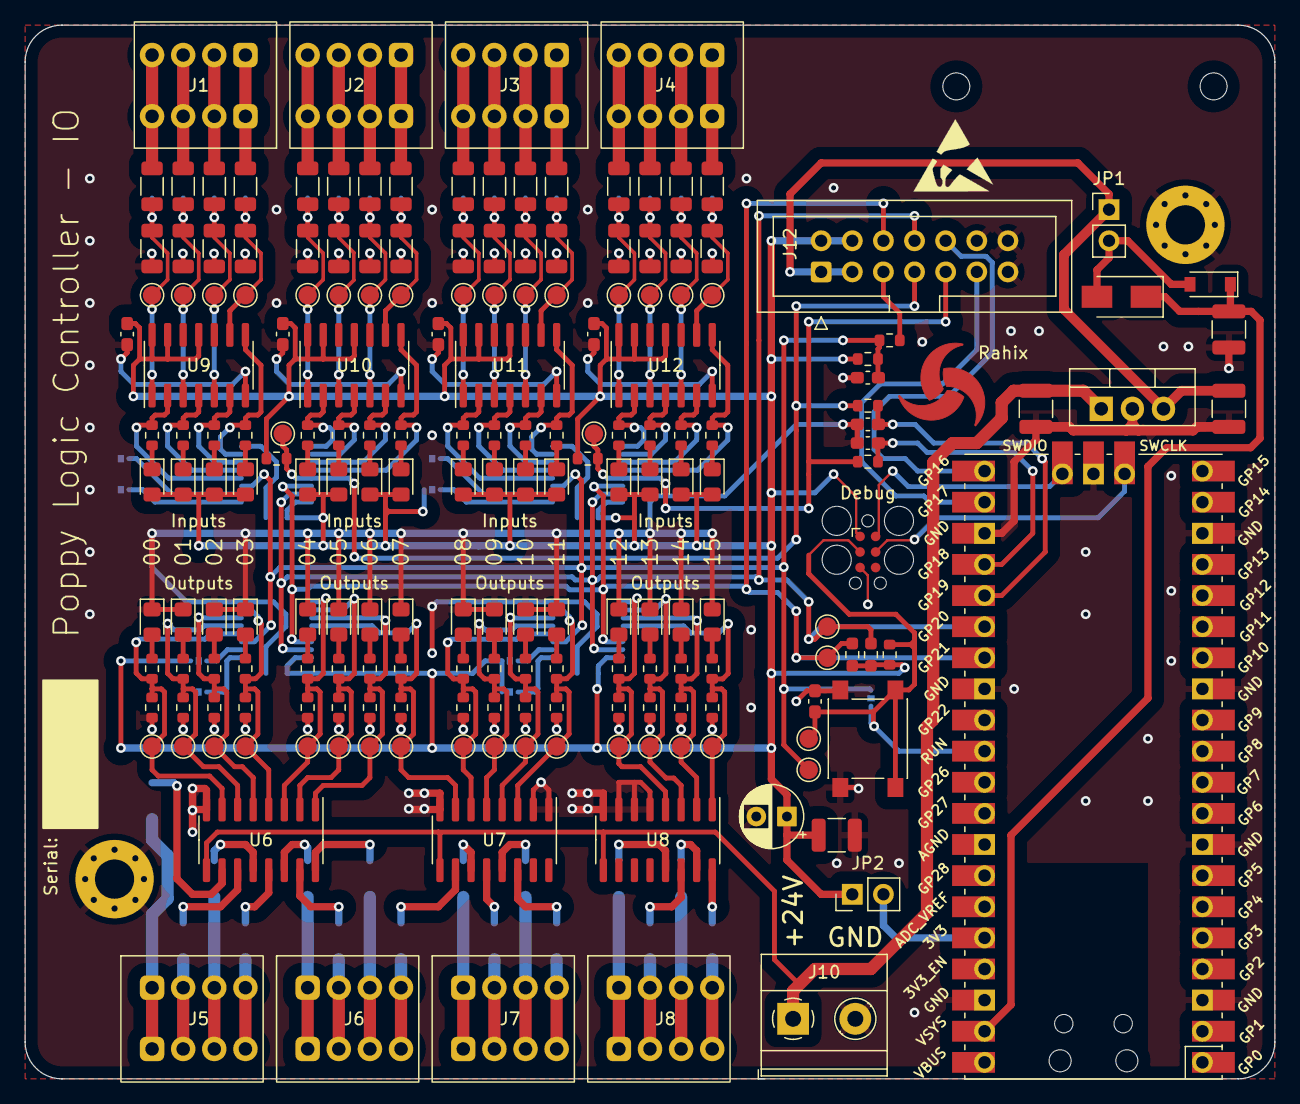
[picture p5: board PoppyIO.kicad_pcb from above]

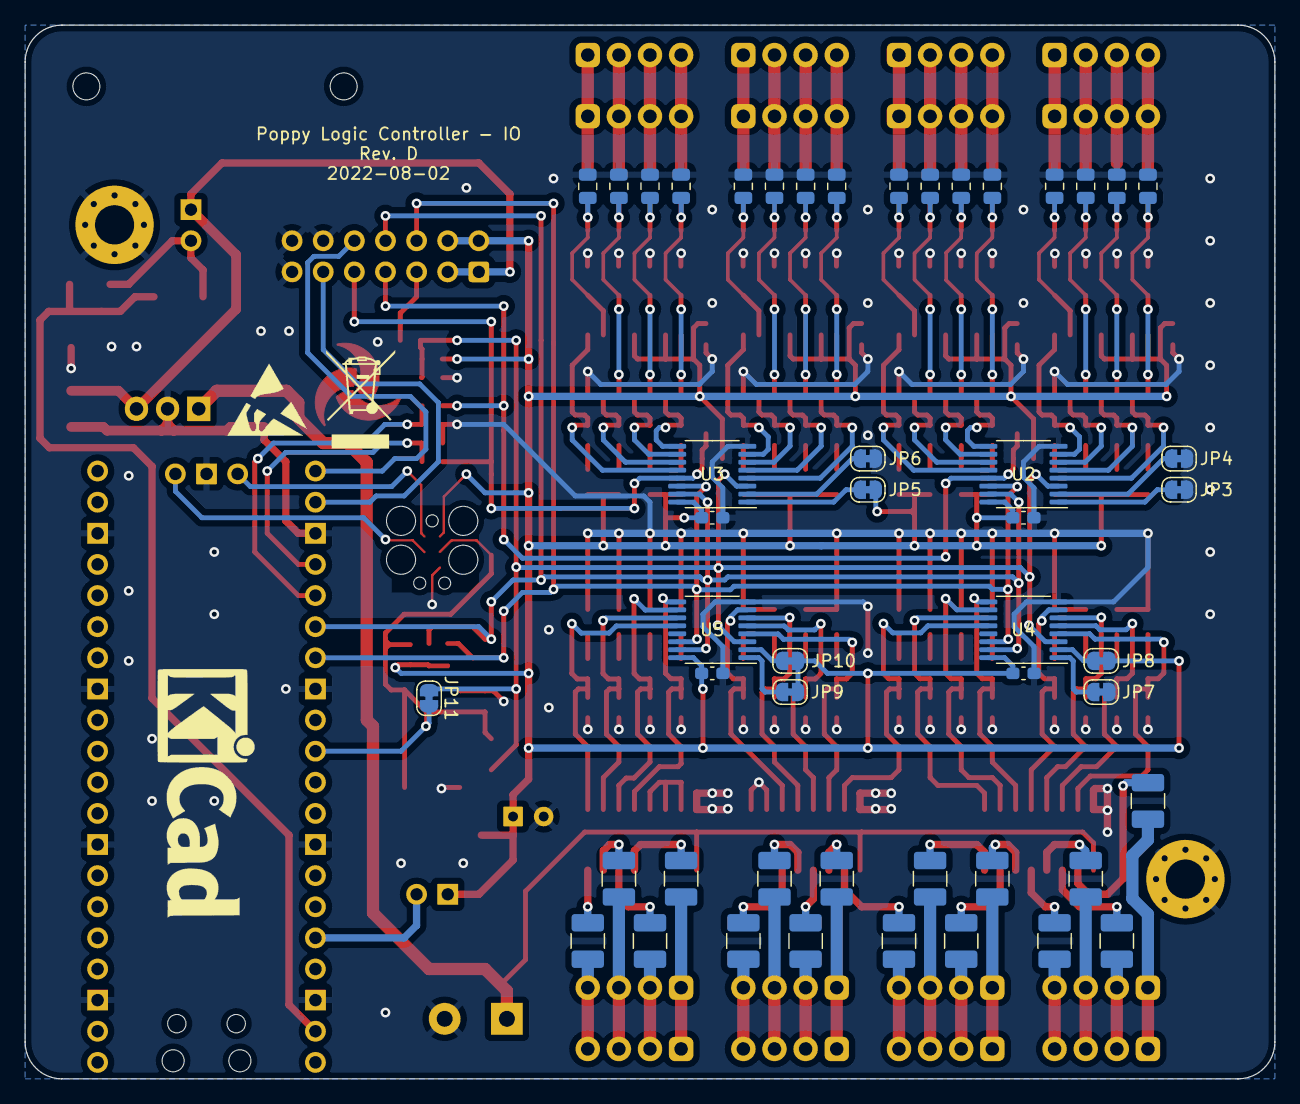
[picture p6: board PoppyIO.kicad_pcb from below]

Board: 2 copper layers, 102.0 x 86.0 mm, 249 parts (49 on the bottom side), 156 nets.

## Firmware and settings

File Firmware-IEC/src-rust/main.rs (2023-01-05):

// SPDX-License-Identifier: MIT
#![no_std]
#![no_main]

use panic_rtt_target as _;
use rtt_target::rprintln;

use embedded_time::rate::*;
use rp_pico::hal;
use rp_pico::hal::pac;

use rmodbus::server::context::ModbusContext;

use embedded_hal::digital::v2::OutputPin as _;

mod matiec;

#[cortex_m_rt::entry]
fn main() -> ! {
    rtt_target::rtt_init_print!();

    rprintln!("Hello Poppy Logic!");

    let mut pac = pac::Peripherals::take().unwrap();
    let _core = pac::CorePeripherals::take().unwrap();

    let mut watchdog = hal::watchdog::Watchdog::new(pac.WATCHDOG);
    let clocks = hal::clocks::init_clocks_and_plls(
        rp_pico::XOSC_CRYSTAL_FREQ,
        pac.XOSC,
        pac.CLOCKS,
        pac.PLL_SYS,
        pac.PLL_USB,
        &mut pac.RESETS,
        &mut watchdog,
    )
    .ok()
    .unwrap();

    let timer = hal::Timer::new(pac.TIMER, &mut pac.RESETS);

    let sio = hal::sio::Sio::new(pac.SIO);
    let pins = rp_pico::Pins::new(
        pac.IO_BANK0,
        pac.PADS_BANK0,
        sio.gpio_bank0,
        &mut pac.RESETS,
    );

    let i2c0 = hal::i2c::I2C::i2c0(
        pac.I2C0,
        pins.gpio20.into_mode(),
        pins.gpio21.into_mode(),
        100.kHz(),
        &mut pac.RESETS,
        clocks.peripheral_clock,
    );

    let bus = shared_bus::BusManagerSimple::new(i2c0);

    let mut inp0 = port_expander::Pca9538::new(bus.acquire_i2c(), false, false);
    let mut inp1 = port_expander::Pca9538::new(bus.acquire_i2c(), true, false);
    let mut out0 = port_expander::Pca9538::new(bus.acquire_i2c(), false, true);
    let mut out1 = port_expander::Pca9538::new(bus.acquire_i2c(), true, true);

    let parts = inp0.split();
    let _i00 = parts.io0.into_inverted().unwrap();
    let _i01 = parts.io1.into_inverted().unwrap();
    let _i02 = parts.io2.into_inverted().unwrap();
    let _i03 = parts.io3.into_inverted().unwrap();
    let _i04 = parts.io4.into_inverted().unwrap();
    let _i05 = parts.io5.into_inverted().unwrap();
    let _i06 = parts.io6.into_inverted().unwrap();
    let _i07 = parts.io7.into_inverted().unwrap();

    let parts = inp1.split();
    let _i08 = parts.io0.into_inverted().unwrap();
    let _i09 = parts.io1.into_inverted().unwrap();
    let _i10 = parts.io2.into_inverted().unwrap();
    let _i11 = parts.io3.into_inverted().unwrap();
    let _i12 = parts.io4.into_inverted().unwrap();
    let _i13 = parts.io5.into_inverted().unwrap();
    let _i14 = parts.io6.into_inverted().unwrap();
    let _i15 = parts.io7.into_inverted().unwrap();

    let parts = out0.split();
    let mut _o00 = parts.io0.into_output().unwrap();
    let mut _o01 = parts.io1.into_output().unwrap();
    let mut _o02 = parts.io2.into_output().unwrap();
    let mut _o03 = parts.io3.into_output().unwrap();
    let mut _o04 = parts.io4.into_output().unwrap();
    let mut _o05 = parts.io5.into_output().unwrap();
    let mut _o06 = parts.io6.into_output().unwrap();
    let mut _o07 = parts.io7.into_output().unwrap();

    let parts = out1.split();
    let mut _o08 = parts.io0.into_output().unwrap();
    let mut _o09 = parts.io1.into_output().unwrap();
    let mut _o10 = parts.io2.into_output().unwrap();
    let mut _o11 = parts.io3.into_output().unwrap();
    let mut _o12 = parts.io4.into_output().unwrap();
    let mut _o13 = parts.io5.into_output().unwrap();
    let mut _o14 = parts.io6.into_output().unwrap();
    let mut _o15 = parts.io7.into_output().unwrap();

    let mut led = pins.led.into_push_pull_output();

    let mut modbus_context = cortex_m::singleton!(:ModbusContext = ModbusContext::new()).unwrap();

    let mut iec_config = matiec::IecConfiguration::new().unwrap();

    led.set_high().unwrap();

    let usb_bus = usb_device::bus::UsbBusAllocator::new(hal::usb::UsbBus::new(
        pac.USBCTRL_REGS,
        pac.USBCTRL_DPRAM,
        clocks.usb_clock,
        true,
        &mut pac.RESETS,
    ));

    let mut serial_port = usbd_serial::SerialPort::new(&usb_bus);

    let usb_id = usb_device::device::UsbVidPid(0xde5f, 0x3d21);
    let mut usb_dev = usb_device::device::UsbDeviceBuilder::new(&usb_bus, usb_id)
        .manufacturer("Rahix")
        .product("Poppy Logic Controller")
        .serial_number("POPPY123")
        .device_class(2)
        .build();

    loop {
        // Read potential changes from modbus
        iec_config.sync_from_modbus(&modbus_context);

        // Reading all inputs
        let pins0 = [&_i00, &_i01, &_i02, &_i03, &_i04, &_i05, &_i06, &_i07];
        let pins1 = [&_i08, &_i09, &_i10, &_i11, &_i12, &_i13, &_i14, &_i15];
        let inputs0 = port_expander::read_multiple(pins0).unwrap_or_else(|e| {
            rprintln!(
                "Failed reading inputs %IX00 - %IX07: {:?} - Faulting to zero state!",
                e
            );
            [false; 8]
        });
        let inputs1 = port_expander::read_multiple(pins1).unwrap_or_else(|e| {
            rprintln!(
                "Failed reading inputs %IX08 - %IX15: {:?} - Faulting to zero state!",
                e
            );
            [false; 8]
        });
        iec_config.write_inputs(inputs0.into_iter().chain(inputs1.into_iter()));

        // Logic evaluation
        let usecs = timer.get_counter();
        iec_config.eval_tick(usecs).unwrap_or_else(|e| {
            rprintln!("Error in logic evaluation: {:?}", e);
        });

        // Writing all outputs
        let mut outputs0 = [false; 8];
        let mut outputs1 = [false; 8];
        iec_config.read_outputs(outputs0.iter_mut().chain(outputs1.iter_mut()));
        let pins0 = [
            &mut _o00, &mut _o01, &mut _o02, &mut _o03, &mut _o04, &mut _o05, &mut _o06, &mut _o07,
        ];
        let pins1 = [
            &mut _o08, &mut _o09, &mut _o10, &mut _o11, &mut _o12, &mut _o13, &mut _o14, &mut _o15,
        ];
        port_expander::write_multiple(pins0, outputs0).unwrap_or_else(|e| {
            rprintln!(
                "Failed writing outputs %QX00 - %QX07: {:?} - State is unknown!",
                e
            );
        });
        port_expander::write_multiple(pins1, outputs1).unwrap_or_else(|e| {
            rprintln!(
                "Failed writing outputs %QX00 - %QX07: {:?} - State is unknown!",
                e
            );
        });

        // Write potential changes to modbus
        iec_config.sync_to_modbus(&mut modbus_context);

        // Wait for next tick
        let _ = led.set_state(((usecs / 1000000) % 2 == 0).into());
        let ticktime: u64 = iec_config.common_ticktime_us().try_into().unwrap();
        let wakeup = usecs + ticktime;

        // While waiting for the next PLC tick, handle USB
        while wakeup > timer.get_counter() {
            if usb_dev.poll(&mut [&mut serial_port]) {
                let mut request_buf = [0x00u8; 256];
                if let Ok(b) = serial_port.read(&mut request_buf) {
                    rprintln!("Message: {:?}", &request_buf[..b]);
                    let mut response = heapless::Vec::<u8, 256>::new();
                    let mut frame = rmodbus::server::ModbusFrame::new(
                        1,
                        &request_buf,
                        rmodbus::ModbusProto::Rtu,
                        &mut response,
                    );
                    if let Err(e) = frame.parse() {
                        rprintln!("Modbus Error: {}", e);
                    } else {
                        if frame.processing_required {
                            let res = match frame.readonly {
                                true => frame.process_read(&modbus_context),
                                false => frame.process_write(&mut modbus_context),
                            };
                            if let Err(e) = res {
                                rprintln!("Modbus Processing Error: {}", e);
                            } else {
                                if frame.response_required {
                                    frame.finalize_response().unwrap();
                                    serial_port.write(&response).unwrap();
                                }
                            }
                        }
                    }
                }
            }
        }
    }
}

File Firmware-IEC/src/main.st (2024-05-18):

(*
 * Sample Program
 * ==============
 * This program demos a simple start-stop circuit where the start and stop
 * buttens have to be held for 0.8s before the operation is performed.  While a
 * button is pressed, an indicator blinks to give immediate feedback.
 *)

{#include "blink.st"}

PROGRAM MAIN
    VAR (* Inputs *)
        xBtnStart           AT %IX08:   BOOL;
        xBtnStop            AT %IX09:   BOOL;

        (* Can be controlled via modbus coils 0 and 1 *)
        xBtnStartModbus     AT %MX00:   BOOL;
        xBtnStopModbus      AT %MX01:   BOOL;
    END_VAR
    VAR (* Outputs *)
        xIndicatorOrange    AT %QX08:   BOOL := FALSE;
        xIndicatorGreen     AT %QX09:   BOOL := FALSE;
        xIndicatorActive    AT %QX15:   BOOL;

        xMotor              AT %QX00:   BOOL := FALSE;
    END_VAR
    VAR (* Variables *)
        xRunning:                       BOOL;
        xWaiting:                       BOOL;
        tmrStart:                       TON;
        tmrStop:                        TON;
        fbBlink:                        FB_Blink;
    END_VAR
    VAR_TEMP
        xWaitingStart:                  BOOL;
        xWaitingStop:                   BOOL;
    END_VAR

    fbBlink(tOnDelay := t#300ms, tOffDelay := t#300ms);
    tmrStart(IN := xBtnStart OR xBtnStartModbus, PT := t#800ms);
    tmrStop(IN := xBtnStop OR xBtnStopModbus, PT := t#800ms);

    xWaitingStart := tmrStart.IN AND NOT tmrStart.Q;
    xWaitingStop := tmrStop.IN AND NOT tmrStop.Q;
    xWaiting := xWaitingStart OR xWaitingStop;

    xRunning := (tmrStart.Q OR xRunning) AND NOT tmrStop.Q;

    xMotor := xRunning;

    xIndicatorGreen := xRunning;
    xIndicatorOrange := xWaiting AND fbBlink.Q;
    xIndicatorActive := fbBlink.Q;
END_PROGRAM

(*
 * It is important to keep this configuration named `STD_CONF` and the resource
 * named `STD_RESOURCE`.  Everything else can be modified. For example, you can
 * add new tasks or change the interval here.
 *)
CONFIGURATION STD_CONF
    RESOURCE STD_RESOURCE ON POPPY_LOGIC_CONTROLLER
        TASK taskMain(INTERVAL := T#50ms, PRIORITY := 0);
        PROGRAM INST0 WITH taskMain : MAIN;
    END_RESOURCE
END_CONFIGURATION

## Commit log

2022-04-01 hw: lib: Import RP-Pico library
    Import symbols and footprints for the Raspberry-Pi Pico from
    https://github.com/ncarandini/KiCad-RP-Pico
    at commit dc6f9b9f213d ("Update Install instructions.md").
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2022-04-01 hw: io: Add libraries
    [PoppyIO.kicad_sch]
2022-04-01 hw: io: Work on 24 VDC inputs and outputs
    [PoppyIO.kicad_sch, inputs.kicad_sch, outputs.kicad_sch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]
2022-04-01 hw: io: Updates
    [PoppyIO.kicad_sch, inputs.kicad_sch, outputs.kicad_sch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]
2022-04-01 hw: io: Single sheet
    [PoppyIO.kicad_sch, inputs.kicad_sch, outputs.kicad_sch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]
2022-04-01 hw: io: Initial PCB shape and design rules
    [PoppyIO.kicad_pcb]
2022-04-01 hw: io: Output drivers and other things
    [PoppyIO.kicad_sch]
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2022-04-02 hw: lib: Update pico pin types
    The 3V3 pin is a power output and one GND pin was erroneously specified
    as "bidirectional".
2022-04-02 hw: io: Annotate
    [PoppyIO.kicad_sch]
2022-04-02 hw: io: Footprints
    [PoppyIO.kicad_sch]
2022-04-02 hw: io: Some PCB planning
    [PoppyIO.kicad_pcb]
2022-04-02 hw: ui: Adjust connector pin ordering
    [PoppyIO.kicad_pcb, PoppyIO.kicad_sch]
2022-04-02 hw: io: More layout improvements
    Reorder driver pins
    [PoppyIO.kicad_pcb, PoppyIO.kicad_sch]
2022-04-03 hw: lib: Use official pico 3D model
    This model is much simpler and thus loading times are much shorter.
2022-04-03 hw: io: Update footprints
    [PoppyIO.kicad_sch]
2022-04-03 hw: io: Update PCB
    [PoppyIO.kicad_pcb]
2022-04-03 hw: io: PCB Updates
    [PoppyIO.kicad_pcb, PoppyIO.kicad_sch]
2022-04-03 hw: io: More updates
    [PoppyIO.kicad_pcb, PoppyIO.kicad_sch]
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2022-04-06 hw: io: Switch to ULN2003AD
    [PoppyIO.kicad_pcb, PoppyIO.kicad_sch]
2022-04-10 hw: io: Updates & clean PCB
    [PoppyIO.kicad_pcb, PoppyIO.kicad_sch]
2022-04-13 hw: io: Update schematic
    Different input stage
    [PoppyIO.kicad_sch]
2022-04-14 hw: io: ERC fixes
    [PoppyIO.kicad_sch]
2022-04-14 hw: io: Update schematic
    [PoppyIO.kicad_sch]
2022-04-14 hw: io: Use one more inverter IC
    This should make layout easier
    [PoppyIO.kicad_sch]
2022-04-14 hw: io: Different fuses
    [PoppyIO.kicad_sch]
2022-04-15 hw: io: Unused ULN2003 inputs
    Tie them to GND.
    [PoppyIO.kicad_sch]
2022-04-22 hw: io: Start PCB layout for real this time
    [PoppyIO.kicad_pcb]
2022-04-22 hw: io: sch: Reorder series resistors for output LEDs
    This helps with routing.
    [PoppyIO.kicad_sch]
2022-04-22 hw: io: More PCB planning
    [PoppyIO.kicad_pcb]
2022-04-22 hw: io: Board settings
    [PoppyIO.kicad_pcb]
2022-04-22 hw: io: PCB layout
    [PoppyIO.kicad_pcb]
2022-04-22 hw: io: More PCB layout
    [PoppyIO.kicad_pcb, PoppyIO.kicad_sch]
2022-04-23 hw: io: Updae PCB and DRC fixes
    [PoppyIO.kicad_pcb]
2022-04-23 hw: io: Update JP2
    shouldn't be a solder jumper
    [PoppyIO.kicad_pcb, PoppyIO.kicad_sch]
2022-04-23 hw: io: Add footprints for 3V3 decoupling caps
    [PoppyIO.kicad_pcb, PoppyIO.kicad_sch]
2022-04-23 hw: io: Add artwork
    [PoppyIO.kicad_pcb, PoppyIO.kicad_sch]
2022-04-23 hw: io: More PCB tweaks
    [PoppyIO.kicad_pcb]
2022-04-24 hw: lib: Add footprint for TO-220-3 with clearance
    This allows to mount LM78xx regulators but also drop-in replacements
    like Gaptec's LMS78 or LMO78 DC/DC step-down supplies.
2022-04-24 hw: io: Add footprints for 24V -> 5V regulator
    In the future, maybe we will want to switch to a unified 24V supply.
    Add footprints for installing a regulator or SPMS to do this.
    [PoppyIO.kicad_pcb, PoppyIO.kicad_sch]
2022-04-24 hw: io: pcb: Fabrication layers
    [PoppyIO.kicad_pcb]
2022-04-24 hw: io: Final touches and prepare revision A
    [PoppyIO.kicad_pcb, PoppyIO.kicad_sch]
2022-04-25 hw: io: Switch to 14-pin IDC
    [PoppyIO.kicad_pcb, PoppyIO.kicad_sch]
2022-04-25 hw: io: Prepare revision B
    [PoppyIO.kicad_pcb, PoppyIO.kicad_sch]
2022-06-26 hw: io: Fix wrong DI resistors
    Copy-paste error - the calculations projected an 820Ω resistor but I
    accidentally used 680Ω instead. This still works but has different
    limiting values...
    [PoppyIO.kicad_pcb, PoppyIO.kicad_sch]
2022-08-02 hw: io: Schematic updates
    - Drop DNP config from LM78xx regulator and capacitors.
    - Removed screw-terminal J9 for external 5V supply.
    - Switched +24VDC screw-terminal to 2-pin variant.
    - Documented J2 meaning.
    [PoppyIO.kicad_sch]
2022-08-02 hw: io: Mirror schematic changes on PCB
    [PoppyIO.kicad_pcb]
2022-08-02 hw: io: PCB cleanup and update J10 footprint
    Choose an appropriate screw-terminal for J10 which has 2 pins and 5.08mm
    pitch.
    [PoppyIO.kicad_pcb, PoppyIO.kicad_sch]
2022-08-02 hw: io: Add Reichelt SKUs for all applicable parts
    [PoppyIO.kicad_pcb, PoppyIO.kicad_sch]
2022-08-02 hw: io: Prepare revision D
    [PoppyIO.kicad_pcb, PoppyIO.kicad_sch]
2022-08-06 hw: io: Generate revision D documents
    - Interactive BOM
    - HTML BOM
    - Schematic PDF
2022-08-07 fw: Add bare-bones Rust firmware
    This is a sample firmware for writing a control program for the Poppy
    Logic Controller in Rust. It uses the `port-expander` [1] crate to
    interact with the I/O expanders.
    [1]: https://crates.io/crates/port-expander
2022-08-07 fw: Add bare-bones MicroPython firmware
    This is a sample driver for writing controls programs for the Poppy
    Logic Controller in MicroPython.
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2022-09-01 fw: iec: Integrate modbus RTU server
    The server is not connected to the PLC runtime yet so register changes
    will not have any effect. It is visible as a USB-Serial device over
    USB.
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
